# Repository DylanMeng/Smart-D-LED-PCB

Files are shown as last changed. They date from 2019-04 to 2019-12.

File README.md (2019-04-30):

## Related projects

### [ Smart D-LED (API)](https://github.com/DylanMeng/Smart-D-LED-API)

### [ Smart D-LED (Tower - Clear Edition)](https://github.com/DylanMeng/Smart-D-LED-Tower)

https://youtu.be/Sv6iBumc9ZM

### [ Smart D-LED (Remote Control)](https://dylogic-design.com/)

https://youtu.be/K5LZp9m322Y

# Smart D-LED (PCB)
PCB

Software, hardware and product development can be time consuming and expensive. If you appreciate the development of Smart-D-LED or any of my projects please consider donating.

Your donation will help me continue the development and support of Smart-D-LED.



## 
The goal of Smart D-LED is to create a universal digital led strip controller that is user-friendly, reliable and awesome. 

### Designed by Dylan Meng
### Reviewed by Paul Brière

**Features**
 - Controlled via Wi-Fi
 - IP address auto-discovery
 - I2S Microphone
 - SPI Flash (used for over the air update)
 - SWD programming port
 - 2x User button
 - 2x Port  for 3-wire or 4-wire digital led strip 
	 - duplicate – same animation on both ports
 - 5V (DC  Jack)
 
**Specifications**
- Power option
	- Internal power (DC Jack) 
		- 7A max!
	- External power (D-LED port) 

- More informations about the PCB will be added soon!

## Release History

- 1.0.1 (TO-DO)
	- Optimize micro USB connector footprint  
	- Optimize DC jack footprint 
	- Add direction on SWD/JTAG connector footprint
	- Prepare/Optimize for automated SMT assembly
	- Remove reset external circuit
	- Remove debug resistors
	- Verify/Update BOM
 - 1.0.0
	 - Inital release (PROTOTYPE)

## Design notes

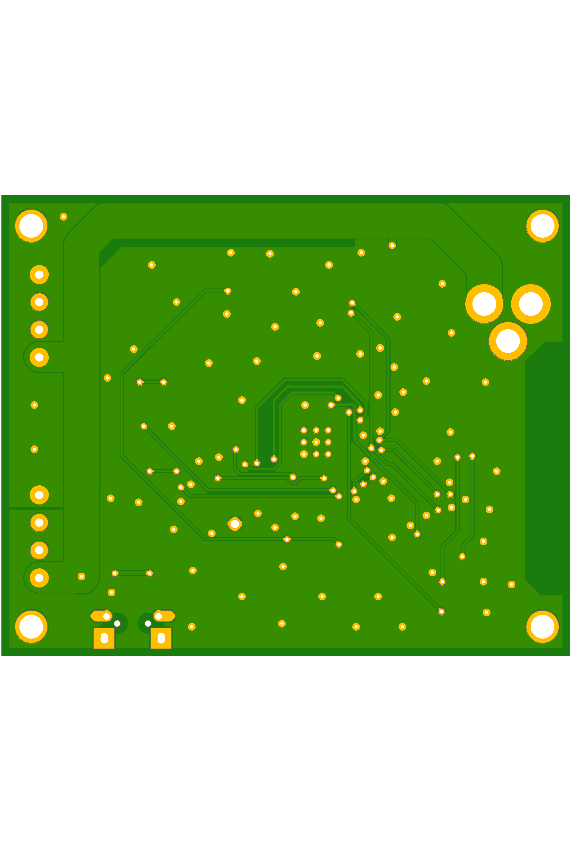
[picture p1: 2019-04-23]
v1.0.0/PCB-BOTTOM.png

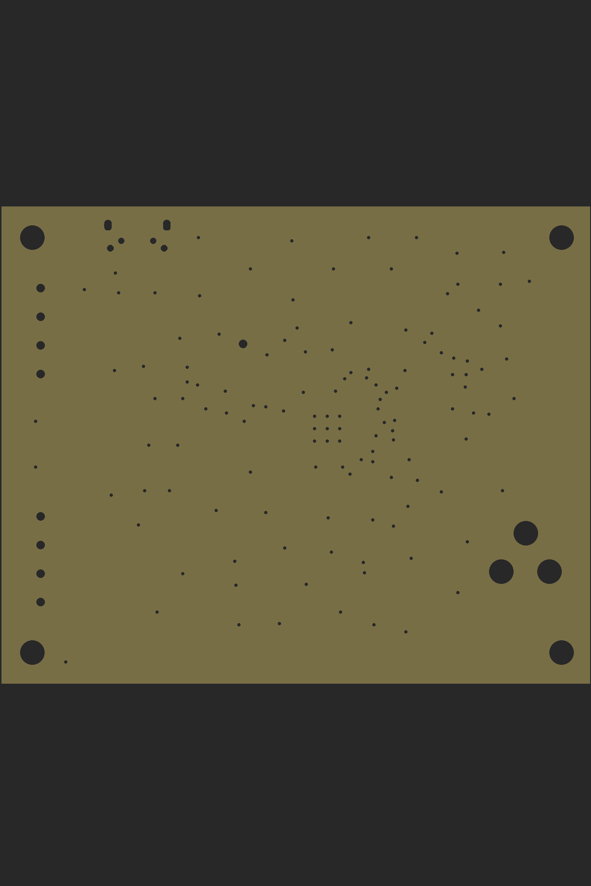
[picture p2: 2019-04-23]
v1.0.0/PCB-DRILLS.png

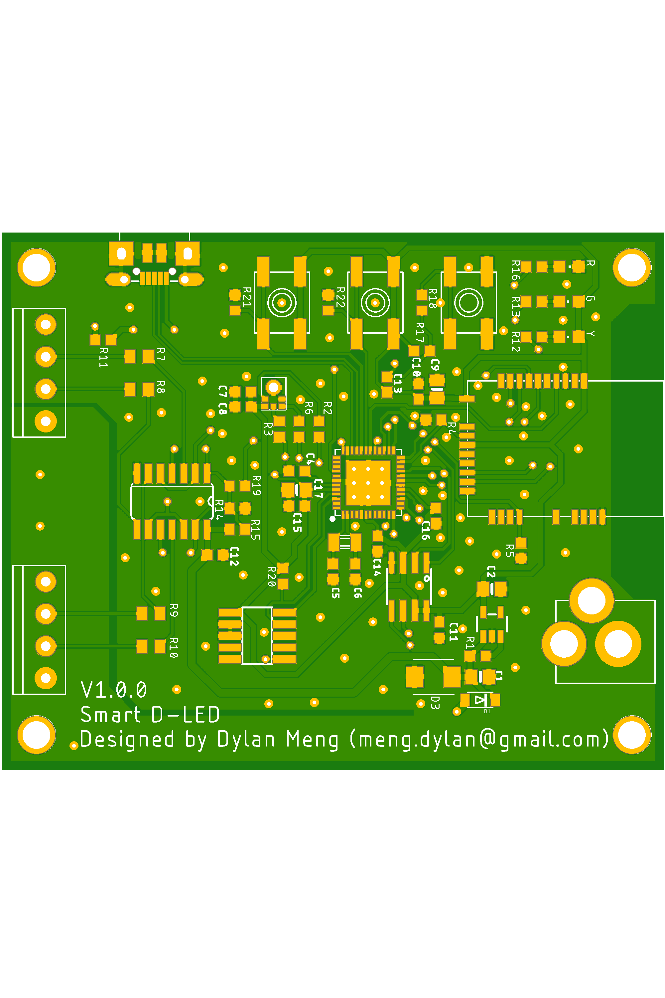
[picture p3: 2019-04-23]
v1.0.0/PCB-TOP.png

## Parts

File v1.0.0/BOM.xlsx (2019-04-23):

Parts Number (PCB) | MPN | Digi-Key P/N | Qty | Value | Package | Description | V1.0.0 | Planned fix for V1.0.1
D1 | MBR120VLSFT1G | MBR120VLSFT1GOSCT-ND (https://www.digikey.ca/product-detail/en/on-semiconductor/MBR120VLSFT1G/MBR120VLSFT1GOSCT-ND/893874) | 1 |  | SOD-123FL | Diode | OK | X
G | LG R971-KN-1 | 475-1410-1-ND (https://www.digikey.ca/product-detail/en/osram-opto-semiconductors-inc/LG-R971-KN-1/475-1410-1-ND/1802598) | 1 |  | CHIPLED_0805 | LED | OK | X | NOTE-RESET | The reset circuit is a bit overkill and the SAMD21 reset pin already have a pull up. Instead the button will be wired straight from the reset pin to the GND. This change will simplify the assembly.
R | LS R976-NR-1 | 475-1278-1-ND (https://www.digikey.ca/product-detail/en/osram-opto-semiconductors-inc/LS-R976-NR-1/475-1278-1-ND/1642798) | 1 |  | CHIPLED_0805 | LED | OK | X
Y | LY R976-PS-36 | 475-2560-1-ND (https://www.digikey.ca/product-detail/en/osram-opto-semiconductors-inc/LY-R976-PS-36/475-2560-1-ND/1802687) | 1 |  | CHIPLED_0805 | LED | OK | X
X2 | 10118192-0001LF | 609-4613-1-ND (https://www.digikey.ca/product-detail/en/amphenol-icc-fci/10118192-0001LF/609-4613-1-ND/2785378) | 1 |  | MICROBUILDER_4UCONN_20329_V2 | USB Connectors | Footprint / Part *not optimal* | NOTE-USB
R7, R8, R9, R10 | RC0805JR-070RL | 311-0.0ARTR-ND (https://www.digikey.ca/product-detail/en/yageo/RC0805JR-070RL/311-0.0ARTR-ND/728216) | 4 | 0R | R0805 | RESISTOR, American symbol | OK | NOTE-LED-PORT-R
D3 | SMBJ6.5CA-13-F | SMBJ6.5CA-FDICT-ND (https://www.digikey.ca/product-detail/en/diodes-incorporated/SMBJ6.5CA-13-F/SMBJ6.5CA-FDICT-ND/816092) | 1 |  | SMBJ | Suppressor diode | OK | X
R11, R19 | RC0603JR-070RL | 311-0.0GRCT-ND (https://www.digikey.ca/product-detail/en/yageo/RC0603JR-070RL/311-0.0GRCT-ND/729622) | 2 | 0R | R0603 | RESISTOR, American symbol | OK | X | NOTE-DC-JACK | The DC jack port footprint is not ideal. Installation required a lot of solder. Proposed fix: change manufacturer or maybe adjust the footprint pad size.
R1, R4, R5, R14, R15 | RC0603JR-07100KL | 311-100KGRCT-ND (https://www.digikey.ca/product-detail/en/yageo/RC0603JR-07100KL/311-100KGRCT-ND/729645) | 5 | 100k | R0603 | RESISTOR, American symbol | OK | X
C7, C10, C11, C12, C14, C15, C16 | 160R14W104KV4T | 709-1153-1-ND (https://www.digikey.ca/product-detail/en/johanson-dielectrics-inc/160R14W104KV4T/709-1153-1-ND/1859485) | 7 | 100nF | MICROBUILDER_0603-NO | Ceramic Capacitors | OK | X
R21, R22 | RC0603JR-0710KL | 311-10KGRCT-ND (https://www.digikey.ca/product-detail/en/yageo/RC0603JR-0710KL/311-10KGRCT-ND/729647) | 2 | 10k | R0603 | RESISTOR, American symbol | OK | X
C1, C2, C9, C17 | CL21A106KPFNNNG | 1276-6456-1-ND (https://www.digikey.ca/product-detail/en/samsung-electro-mechanics/CL21A106KPFNNNG/1276-6456-1-ND/5958084) | 4 | 10uF | MICROBUILDER_0805-NO | Ceramic Capacitors | OK | X
X4 | 20021121-00010C4LF | 311-10KGRCT-ND (https://www.digikey.ca/product-detail/en/amphenol-icc-fci/20021121-00010C4LF/609-3695-1-ND/2209147) | 1 | 1365-10 | 1365-10 | DUAL ROW STRAIGHT HEADER 1364 SERIES. 1.27mm x 1.27mm. Without Fixing Post. SMT | Footprint / Part *not optimal* | NOTE-SWD-PORT
LED-STRIP-A, LED-STRIP-B | 395021004 | WM7772-ND (https://www.digikey.ca/product-detail/en/molex/0395021004/WM7772-ND/1280623) | 2 | 1X4-3.5MM | 1X04-3.5MM | 4-pin connector | OK | X | NOTE-SWD-PORT | There is no way to know which side to connect the SWD programming port. Proposed fix: change footprint silkscreen to help align the programming port in the right direction and position.
R12, R13, R16, R20 | RC0603JR-071KL | 311-1.0KGRCT-ND (https://www.digikey.ca/product-detail/en/yageo/RC0603JR-071KL/311-1.0KGRCT-ND/729624) | 4 | 1k | R0603 | RESISTOR, American symbol | OK | X
C4 | CL10B105KP8NNNC | 1276-1946-1-ND (https://www.digikey.ca/product-detail/en/samsung-electro-mechanics/CL10B105KP8NNNC/1276-1946-1-ND/3890032) | 1 | 1uF | MICROBUILDER_0603-NO | Ceramic Capacitors | OK | X
U$2 | PJ-102A | CP-102A-ND (https://www.digikey.ca/product-detail/en/cui-inc/PJ-102A/CP-102A-ND/275425) | 1 | 2.1MMJACKTHM | PJ-102A | 2.1mm x 5.5mm THM DC jack with internal switch. Digikey part #PJ-102A, 4UCON part #05537 | Footprint / Part *not optimal* | NOTE-DC-JACK
C13 | CC0603JRNPO9BN101 | 311-1069-1-ND (https://www.digikey.ca/product-detail/en/yageo/CC0603JRNPO9BN101/311-1069-1-ND/302979) | 1 | 100pF | MICROBUILDER_0603-NO | Ceramic Capacitors | OK | NOTE-RESET
C8 | CL10C201JB8NNNC | 1276-2222-1-ND (https://www.digikey.ca/product-detail/en/samsung-electro-mechanics/CL10C201JB8NNNC/1276-2222-1-ND/3890308) | 1 | 200pF | MICROBUILDER_0603-NO | Ceramic Capacitors | OK | X
C5, C6 | C0603C220J4GAC7867 | 399-15377-1-ND (https://www.digikey.ca/product-detail/en/kemet/C0603C220J4GAC7867/399-15377-1-ND/7386775) | 2 | 22pF | MICROBUILDER_0603-NO | Ceramic Capacitors | OK | X | NOTE-USB | The USB part and footprint are not optimal together. Change the part or fix footprint.
R17 | RC0603JR-072K2L | 311-2.2KGRCT-ND (https://www.digikey.ca/product-detail/en/yageo/RC0603JR-072K2L/311-2.2KGRCT-ND/729676) | 1 | 2k2 | R0603 | RESISTOR, American symbol | OK | NOTE-RESET
X3 | ECS-.327-12.5-34B-TR | XC1617CT-ND (https://www.digikey.ca/product-detail/en/ecs-inc/ECS-.327-12.5-34B-TR/XC1617CT-ND/1693786) | 1 | 32.768 | XTAL3215 | Low cost SMT crystals, no capacitors included | OK | X
R18 | RC0603JR-07330RP | YAG1314CT-ND (https://www.digikey.ca/product-detail/en/yageo/RC0603JR-07330RP/YAG1314CT-ND/4935427) | 1 | 330R | R0603 | RESISTOR, American symbol | OK | NOTE-RESET
R2, R3, R6 | RC0603JR-0751RL | 311-51GRCT-ND (https://www.digikey.ca/product-detail/en/yageo/RC0603JR-0751RL/311-51GRCT-ND/729750) | 3 | 51R | R0603 | RESISTOR, American symbol | OK | X
IC3 | SN74HC125DR | 296-1192-1-ND (https://www.digikey.ca/product-detail/en/texas-instruments/SN74HC125DR/296-1192-1-ND/404905) | 1 | 74HC125D | SO14 | Quad bus BUFFER, 3-state | OK | X
U1 | AP2112K-3.3TRG1 | AP2112K-3.3TRG1DICT-ND (https://www.digikey.ca/product-detail/en/diodes-incorporated/AP2112K-3.3TRG1/AP2112K-3.3TRG1DICT-ND/4505257) | 1 | AP2112K-3.3 | MICROBUILDER_SOT23-5 | SOT23-5 Fixed Voltage Regulators | OK | X | NOTE-LED-PORT-R | These resistors were used for debugging and protection test on different digital LED strip type. Further investigation would need to be done but for automated assembly, they could be removed for cost reason.
SW1, SW2, SW3 | EVQ-Q2U03W | P12955SCT-ND (https://www.digikey.ca/product-detail/en/panasonic-electronic-components/EVQ-Q2U03W/P12955SCT-ND/762945) | 3 | EVQ-Q2U03W | EVQ-Q2 | SMT 6mm switch, EVQQ2 series | OK | X
U$1 | ATSAMD21G18A-MUT | ATSAMD21G18A-MUTCT-ND (https://www.digikey.ca/product-detail/en/microchip-technology/ATSAMD21G18A-MUT/ATSAMD21G18A-MUTCT-ND/4878880) | 1 | MICROBUILDER_ATSAMD21J_QFN | MICROBUILDER_TQFN48_7MM | MCU | OK | X
X1 | ATWINC1500-MR210PB | ATWINC1500-MR210PB-ND (https://www.digikey.ca/product-detail/en/microchip-technology/ATWINC1500-MR210PB/ATWINC1500-MR210PB-ND/5322332) | 1 | MICROBUILDER_ATWINC1500_MR210PA | MICROBUILDER_ATWINC1500_MR210PA | ATWINC1500_MR210PA wifi module | OK | X
IC2 | SPH0645LM4H-B | 423-1405-1-ND (https://www.digikey.ca/product-detail/en/knowles/SPH0645LM4H-B/423-1405-1-ND/5332432) | 1 | SPH0645LM4H-B | MICROBUILDER_SPH0645LM4H | I2S MIC | OK | X
U2 | W25Q80DVSNIG TR | W25Q80DVSNIGCT-ND (https://www.digikey.ca/product-detail/en/winbond-electronics/W25Q80DVSNIG-TR/W25Q80DVSNIGCT-ND/5253805) | 1 | W25Q80DVSNIG | SOIC8_150MIL | SOIC8 SPI Flash | OK | X

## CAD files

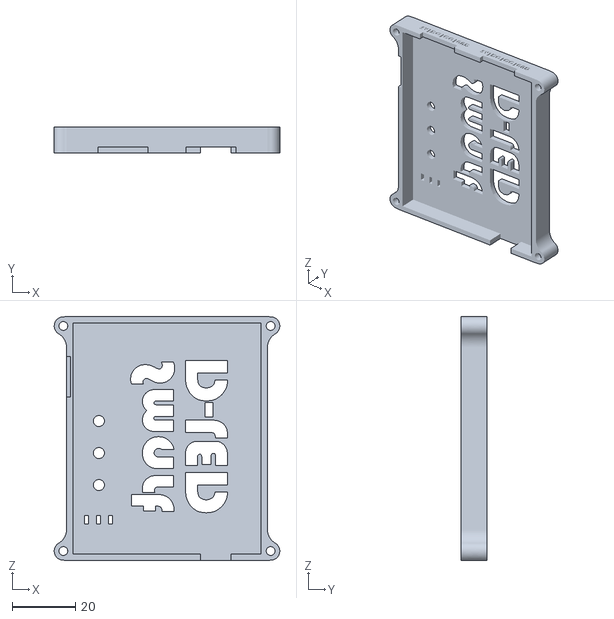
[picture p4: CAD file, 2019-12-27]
v1.0.0/3d_print_enclosure/Smart-D-LED-CASE-TOP_V1.stl
71.5 x 8.15 x 77.4

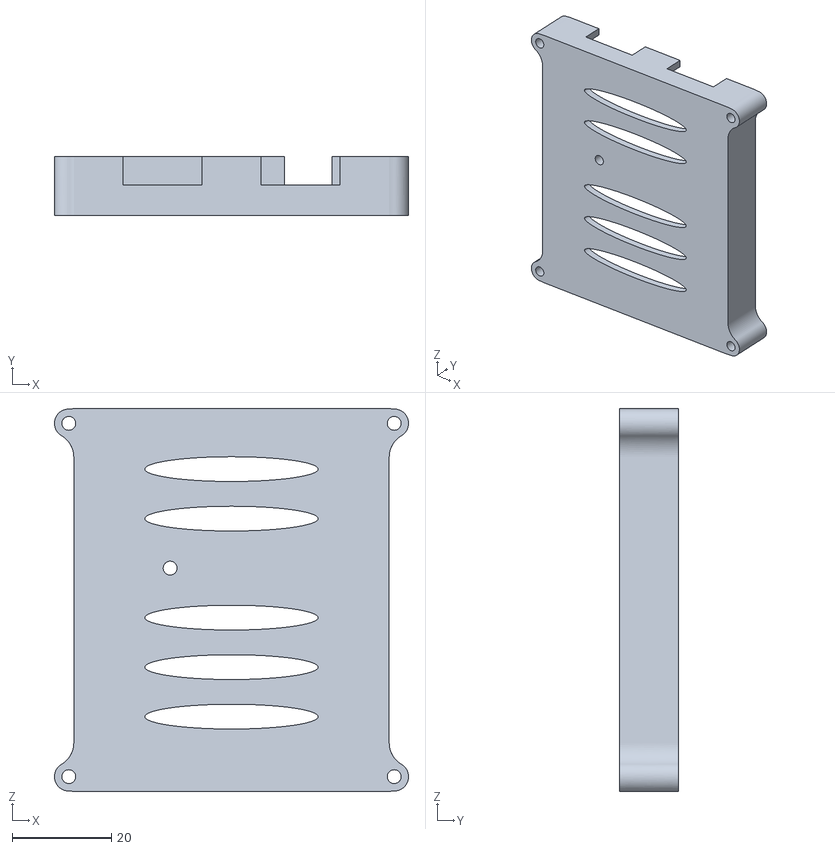
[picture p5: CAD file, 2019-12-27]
v1.0.0/3d_print_enclosure/Smart-D-LED-CASE-BOTTOM_V1.stl
71.5 x 12.0 x 77.4

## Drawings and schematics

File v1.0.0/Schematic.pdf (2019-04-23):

A

A

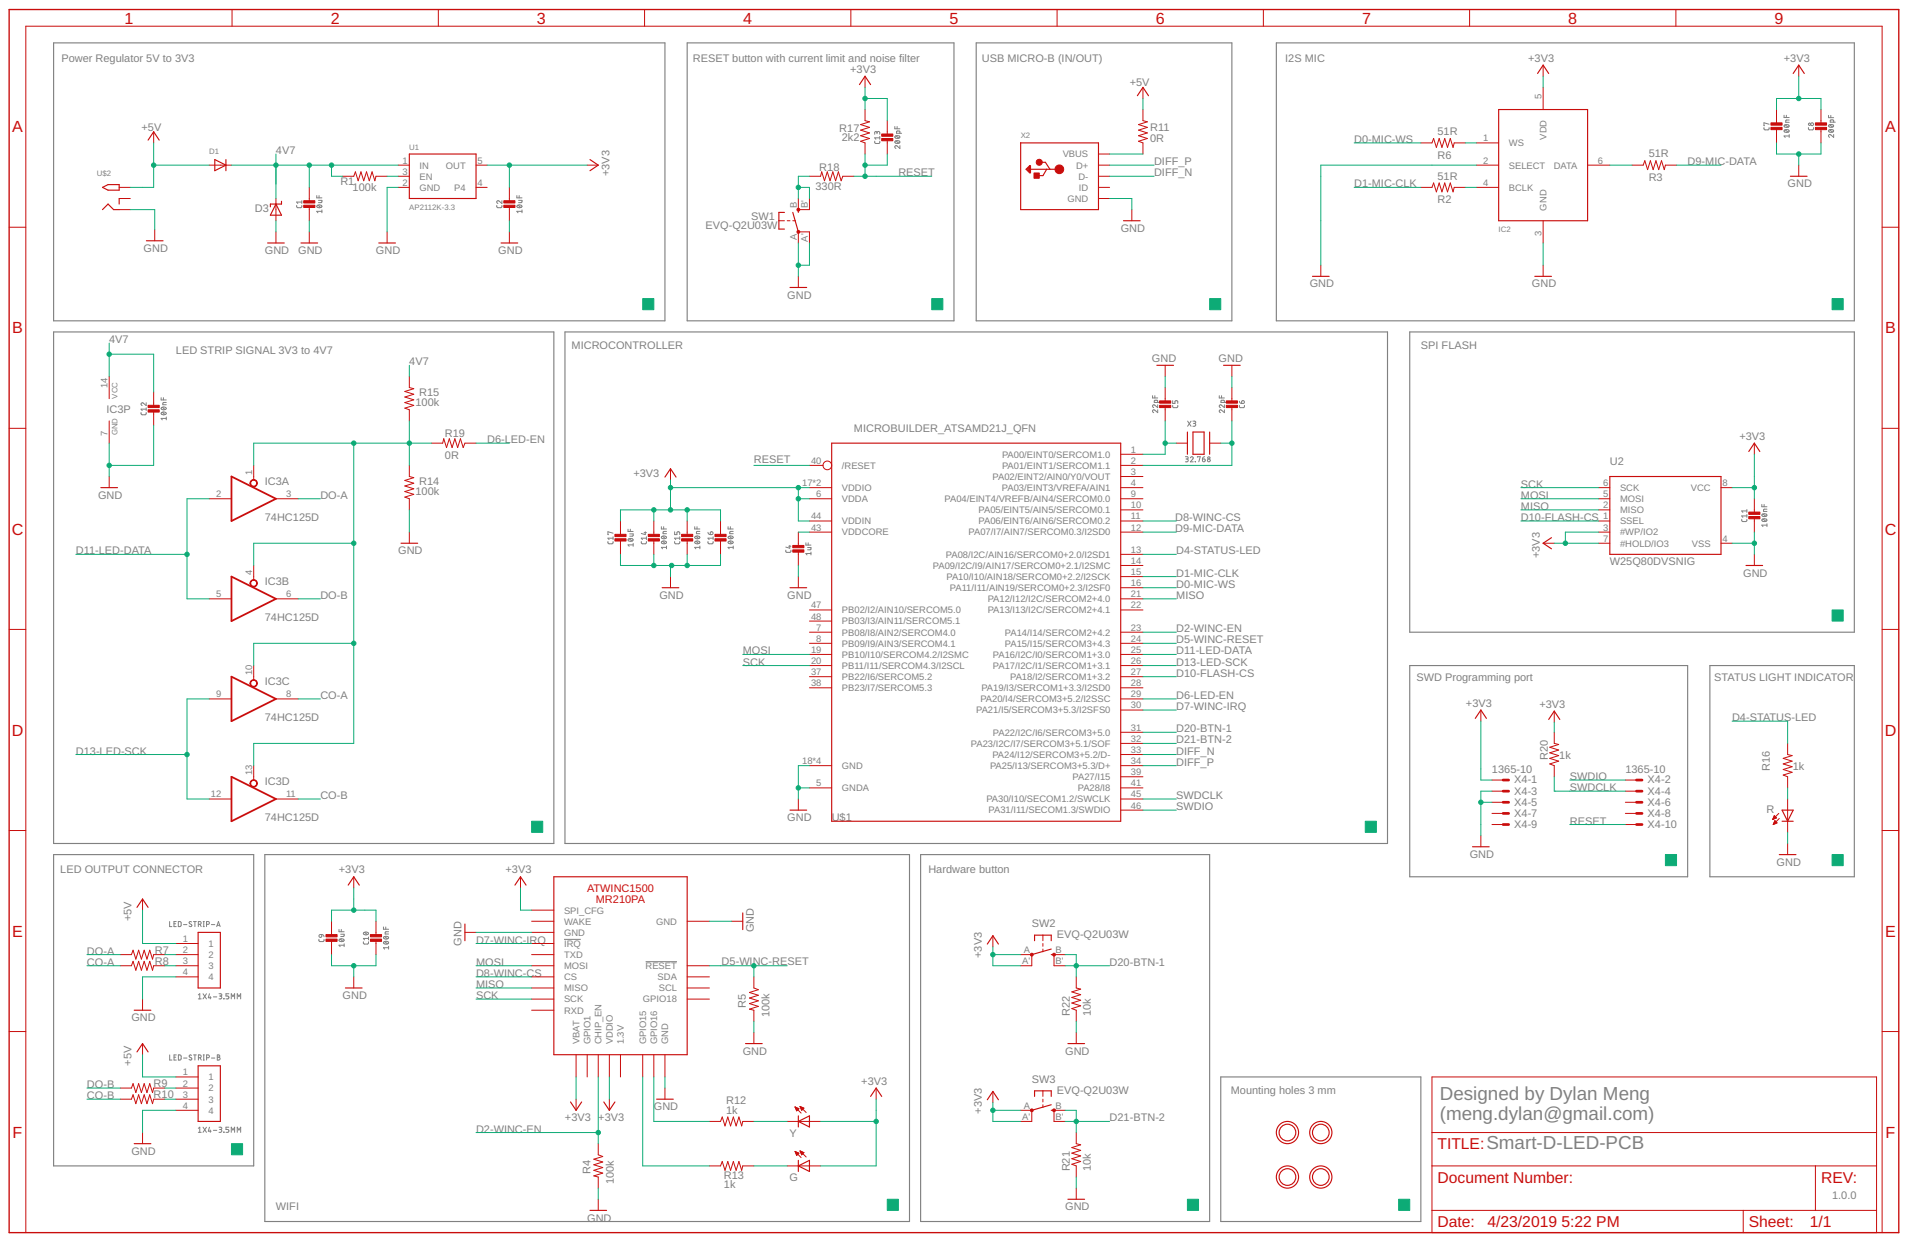
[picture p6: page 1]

RESET button with current limit and noise filter

LED STRIP SIGNAL 3V3 to 4V7

MOSI | 6 | 9

Designed by Dylan Meng
(meng.dylan@gmail.com)
Smart-D-LED-PCB

Document Number: | REV: 1.0.0

Date: 4/23/2019 5:22 PM | Sheet: 1/1

4/23/2019 5:41 PM f=1.30 C:\Users\Dylan\Desktop\pcb\pcb_smart-d-led\SCH_Smart-D-LED.sch (Sheet: 1/1)

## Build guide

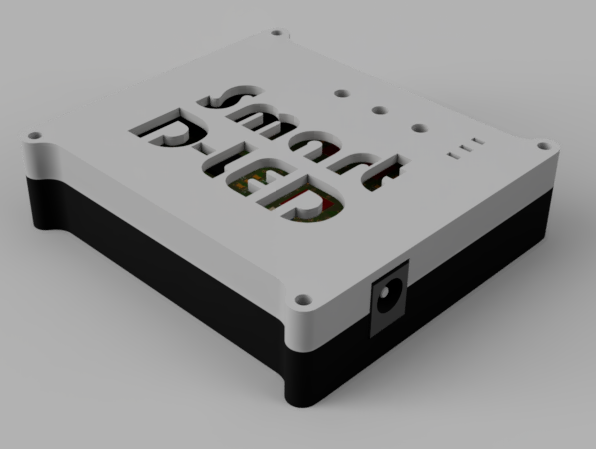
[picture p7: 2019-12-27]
v1.0.0/3d_print_enclosure/Smart-D-LED-CASE-V1_01.png

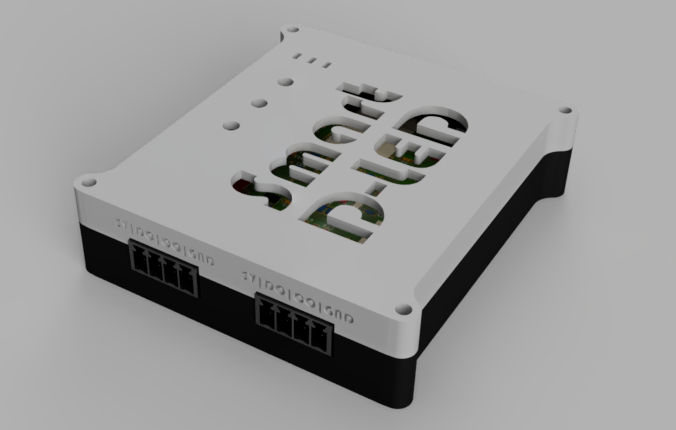
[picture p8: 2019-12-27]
v1.0.0/3d_print_enclosure/Smart-D-LED-CASE-V1_00.png

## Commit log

2019-04-23 Add SCH, GERBER, IMAGE
2019-04-23 Add BOM
    [BOM.xlsx]
2019-04-24 Released hardware now in folder
    [BOM.xlsx]
2019-12-27 Add Smart-D-LED-CASE-V1
    [Smart-D-LED-CASE-BOTTOM_V1.stl, Smart-D-LED-CASE-TOP_V1.stl]
